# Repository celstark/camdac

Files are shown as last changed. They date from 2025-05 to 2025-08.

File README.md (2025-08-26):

# camdac
DSP / DAC and headphone amplifier based on a Raspberry Pi and CamillaDSP
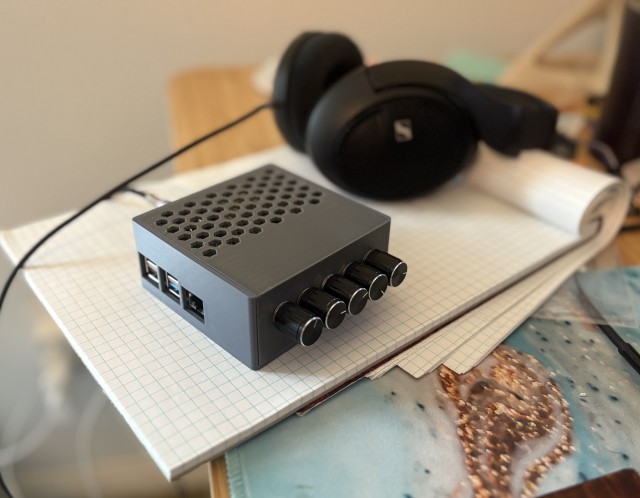
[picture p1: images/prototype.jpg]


**Status**: This is in the "tinkerer" phase. Things are up and running just fine (see the notes.md for the current punch-list). But, expect to do things like ssh onto the device to start up the knob control script (`camdac.py`) and use a browser to the onboard Camilla GUI server to re-define your filters. You don't need the Pi physically hooked to anything but USB power if you want to stream to it. But, you can customize the knobs to do whatever aspects of EQ you like. Heck, you can skip the onboard DAC HAT and just use "Gadget mode" to process from USB to USB.

**August 2025**: Big update here is the addition of a display, a new case to go along with it, and allowing the filter knobs to switch what aspect you're controling (gain, freq, Q, and type)
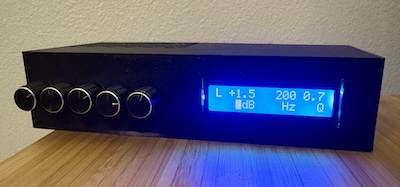
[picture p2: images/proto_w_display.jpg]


## What is it?  Why is it?
I like knobs. I like EQ. When I started in audio, we EQ'ed with knobs. I yearn for that simpler time. So, I made this overly-complex solution to that problem ;)

OK, a better answer.  CamDAC is a project that lets you construct a device to give your audio system stand-alone, fully-customizable DSP processing for things like parametric EQ. It's based off of a Raspberry Pi running [CamillaDSP](https://github.com/HEnquist/camilladsp), a very efficient DSP processing utility. While it runs in software on Linux, macOS, and Windows (meaning you could just run it in software), CamDAC gives you a physical device with physical adjusters. A few use-modes:
- Given that this is a Raspbery Pi, it can house our mount network-based music shares and you can have it directly stream from there with parametric EQ pushing audio out the RCA jacks or the headphone jack
- Given that, you can run Shairplay and stream from your iPhone, iPad, etc. or any other Airplay device and have lossless streaming with parametric EQ
- You can have USB input and USB output, turning this into an inline digital parametric EQ device.  See *Gadget Mode* below.
- Configure this to your heart's content. Got an EQ profile you overall like for your headphones or speakers, but feel, at times, you want a touch more bass or some more "air"?  Have a mood or an album where you just want nothing to do with upper-bass? Assign these filters to the knobs and have this overlay on top of your existing EQ profile.
- No seriously -- to your heart's content.  Want a knob that simultaneously adds a low-shelf and a high-shelf filter at once (make me a V!)? Want one that adjusts the Q of a filter rather than it's amplitude? Heck, want to turn a knob that both adjusts that V shaped response while also adjusting the Q of the slopes and varies the amplitude of a notch centered on 3.14 kHz? Go for it.  You're strange, sure, but go for it.
- *Remember, you can have more filters than knobs*. For example, I've got mine setup right now with 6 filters for my headphones as the basic starting point. In addition to those, I've got 4 more filter knobs giving me several different shelf or peaking filters to play around with. So, I start off with my current go-to EQ setup for these headphones, but have other adjustments I can add in (in addition to giving volume and balance knobs).

## What do I need?
You'll need the following to construct the device:
- A Raspberry Pi 4.  You can likely use others, but it's setup now for the 4B
- (semi-optional): A DAC HAT. This plugs onto the RPi board and gives you RCA and headphone outputs. It's configured now for the [Raspberry Pi DAC+](https://www.raspberrypi.com/products/dac-plus/) (formerly the IQAudio DAC+). If you use this as a USB gadget only (PEQ on USB in to USB out), you don't need this.
- A micro USB card for the RPi.  I got a 64G one for $5 and I've used under 10G on it.
- USB power for the Pi. I'm using some USB-C Apple wall supply I had around. Max it'll need ever is 3A @ 5V, but I've run it happily on a 1.5A 3V supply.
- A case: I've provided STL and SCAD files for what I've made
- Rotary encoders: Just the basic ones (not the modules) are all you need
- A way to wire the encoders to the GPIO pins. I used a simple off-the-shelf GPIO breadboard that made it easy.  More details are in the `GPIO_lines.md` file. But, you'll need a basic soldering setup
- A lack of paralyzing fear when looking at code. I've written a bunch here and more instructions may come, but the whole point here is to be able to customize this and that does mean being able to change things in a text file

All-in, I'm under $100 USD

# OK, where do I start?
## Get your RPi going and CamillaDSP on it
Assuming you've got your parts, you'll need to install the RPi OS, Camilla DSP, and, optionally Shairpoint. Fortunately, someone's written all that up for us and done a great job.  All hail _mdsimon2_!.  Seriously, just go follow [mdsimon2's instructions](https://github.com/mdsimon2/RPi-CamillaDSP). It'll start off having you do things like this once the OS is installed:

```
mkdir ~/camilladsp ~/camilladsp/coeffs ~/camilladsp/configs
wget https://github.com/HEnquist/camilladsp/releases/download/v3.0.1/camilladsp-linux-aarch64.tar.gz -O ~/camilladsp/camilladsp-linux-aarch64.tar.gz
sudo tar -xvf ~/camilladsp/camilladsp-linux-aarch64.tar.gz -C /usr/local/bin/

sudo wget https://raw.githubusercontent.com/mdsimon2/RPi-CamillaDSP/main/camilladsp.service -O /lib/systemd/system/camilladsp.service

... (keep going )

```
I did Steps 1-7 but skipped Step 8 (gadget mode) initially as I didn't have the required hardware (See below -- it's running now). Two big things:
1) **For Sep 7, Enable ALSA Loopback**, you are running in ALSA mode. So, setup that loopback
2) **When it comes to Step 9, Assign the Active Configuration**, use the `CamDAC_config.yml` file here. It's got all you need to get going (see below) 

Note, if you've followed the dfault paths here, on your host machine, you should be able to connect to the CamillaDSP GUI using a web browser on port 5005. This can be super, super handy as you can monitor just what's going on with Camilla.

While we're here, we have one more thing to do. That guide assumes you're using the headphone jack on the Pi board itself. We're using the much nicer [TI 5122](https://www.ti.com/document-viewer/pcm5122/datasheet) one. To do this, we need to turn off the onboard sound by commenting out the audio with `#dtparam=audio=on` in `/boot/firmware/config.txt`. If you get lost here, check the [RPi DAC docs](https://www.raspberrypi.com/documentation/accessories/audio.html) 

While here, you may want to install Shairport. This lets you Airplay (lossless WiFi) to your box.  That's included in [mdsimon2's Streamer Applications](https://github.com/mdsimon2/RPi-CamillaDSP?tab=readme-ov-file#streamer-applications) section of the instructions.

FWIW, setting up a Remote Desktop (VNC is baked in) is optional. I found it handy when trying to debug my audio devices a bit as it gave an easy way of changing the default, but it really is just optional. For all the development work, I'm just using VSCode and an ssh remote onto the device. Currently, if you do the VNC route, actually use TigerVNC. Remmina and some others have issues.

Once everything is set and you've done a reboot, test it out.  A quick test for Camilla's basic operation and the DAC HAT's operation, try this on the command line: `speaker-test -D hw:Loopback,1 -c 2 -r 44100 -F S32_LE`.  You're telling Linux to send pink noise to the ALSA Loopback device. The `CamDAC_config.yml` that should be running in your Camilla DSP interface is listening on the hw:Loopback and sending to the DAC HAT. In their lingo, the capture device is `hw:0` and the DAC HAT is `hw:CARD=DAC,DEV=0`. A [screencap](images/camilla_config.png) sample running configuration in the Camilla DAC GUI is provided here in the images folder. If things are working, don't worry yet about the other parameters. You're doing your're processing at 88.1k and you're setup to adjust the sample rate as needed. There's plenty of time to geek out on this later after going over the main [Camilla DSP docs](https://github.com/HEnquist/camilladsp)

## Install pyCamillaDSP
The code here uses [pyCamillaDSP](https://henquist.github.io/pycamilladsp/config/) as a Python front-end to Camilla's web-sockets so we can control Camilla. If that means nothing to you, forget I typed it. We need a Python library to be installed so that our code can work. Unlike a simple pip-based install, this *really* wants to be in a virtual environment and not be installed into the main system python. Here's how you do that and install the library (make sure though to include the system packages or you'll miss out on all the RPi bits we need).
```
python -m venv  --system-site-packages ~/camilladsp/.venv
source ~/camilladsp/.venv/bin/activate
pip install git+https://github.com/HEnquist/pycamilladsp.git
```

With that done, as you work with the code, you'll need to either first activate the environment (that `source ~/camilladsp/.venv/bin/activate` bit) or just tell Linux to use that environment's python and run the code with `~/camilladsp/.venv/bin/python some_script.py`. So, to run the CamDAC now, before we have any service running, you can just `~/camilladsp/.venv/bin/python camdac.py`

## Wire up your encoders
I've covered my configuration of the GPIO lines and how I wired things up in the [GPIO_lines.md](GPIO_lines.md) file. Head over there for the details.

## Case
The case came from [Pieterbos82](https://www.thingiverse.com/thing:4753525) on Thingiverse originally.  I took his SCAD code, fumbled my way through SCAD, and revised it.  Notably, I turned off the Neutrik / XLR bits, reworked the DAC HAT spacing for the IQAudio / RaspberyPi branded DAC boards, and added holes in the "front" for our controls. The STL and SCAD files are all included here for printing or modification.

## Test out your hardware
Once built, you'll want to make sure the encoders are working correctly.  The supplied `encoder_tester.py` will do this for you. Run it with `~/camilladsp/.venv/bin/python ~/camdac/encoder_tester.py`.  You should be able to adjust all your knobs and have the code report your chages. Press each button and check it too. Hold down the first knob to exit (or Ctrl-C)

# Customizing your rig
Still here?  Now, for the fun.  It's time to make those knobs do what you want.  There are two places to work in and consider here: the `camdac.py` file that actually talks to CamillaDSP and the `CamDAC_config.yml` file.

## The CamDAC_config.yml file
This is the configuration file for CamillaDSP tied to the project. After installing Camilla DSP, copy it into the `~camilladsp/configs/` folder if it's not already there from above.  Assuming you've got the CamillaDSP GUI running (you did install that above right? - it'll be somewhere like http://raspberrypi.local:5005/gui), go to the Files tab, load this up and set it to be "active" (starred)

You can customize this in a text editor or in the CamillaDSP GUI. There are a few key bits here:
- We have filters named "Filt1", "Filt2", ... "Filt5".  These are ones, by default, configured to be accessible by `camdac.py` and be adjusted with the knobs. You can use different names if you like, but just know that `camdac.py` needs to send configuration updates for the active config that match these names.  Best to set their default gain, initially at least, to zero. But, **here is where you actually set things like the frequency and Q**.  The `camdac.py`, by default, just changes the amplitude of these filters.
- There's an example "LShelf" filter. You'll have some filters you want always in the pipeline.  Think of these as your "base configuration" if you like and the FiltN as what rides on top of these. Setup whatever you like here in the Filters section and add it to the Pipeline as well.
- We have separate volume filters for L and R to give our balance. They work by using the Aux sliders to reduce gain in one or the other channel

## The camdac.py file
At some point, this will be tied to a system service, but for now, it's just a file to run manually. But, it does all our heavy-lifting.  At the outset, we have some simple constants saying how much we want each click of the encoder to adjust the volume or an EQ filter:
```
volume_step = 0.25
balance_step = 0.05
eq_step = 0.5
```
After that, you'll start seeing some notes to you saying where you're more or less likely to find things to customize. The first one to look at is to check the `encpins` and adjust if you put your knobs on different GPIO lines. Next, you'll see declarations of our kobs.

That section lays out some defaults to pay attention to. Most notably, the `name` attribute says what each knob starts off acting like. You can adjust things here if you like, but further down, we get to the "Setup what the knobs and buttons actually do" where you can override things.

The key to note here is that how the knob behaves is goverend by the `name` attribute. `Volume` makes it control the main volume.  `VolBal` has it toggle (based on press) between Volume and Balance. Anything else is the name of a filter it'll try to control the amplitude of.  We trap both clockwise and counter-clockwise events so we can know the direction and we turn what `gpiozero` normally has as just simple functions into lambda ones so that we cana include optional parameters with info about not just the `gpiozero` encoder that made the event, but that direction and our higher-level Encoder class that it's tied to.  I'm passing all this in to give us the most flexibility in what we want the knobs to be able to do.

# Misc bits
A few utilities to help here:
- `encoder_tester.py`: Lets you watch your encoder events to make sure all is working
- `fetch_config.py`: Dumps the running configuration to files and shows you an EQAPO style filter configuration

# Gadget mode
You don't need to use any onboard DAC. You can just as well use the device as an in-line digitial PEQ device. 

- Figure your current DAC's capable modes. If it's plugged into a Linux box `aplay -l` to list the devices. In my case, the Fulla was on card1.  Then, see what modes are supported `cat /proc/asound/card1/stream0`.  So, all typical suspects from 44100 - 384000, 16_LE, 24_3LE, and 32_LE

- Set the RPi up to run in gadget mode and offer up an audio interface. Instructions are ocming from [mdsimon2](https://github.com/mdsimon2/RPi-Camilla). It's also good to have [DeLub's post on ASR](https://www.audiosciencereview.com/forum/index.php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) on hand (we're well past the need to compile anything in that thread though). For now, I'm just going to offer up 44100 like mdsimon2 did 
```
echo 'dtoverlay=dwc2' | sudo tee -a /boot/firmware/config.txt > /dev/null
echo -e 'dwc2\ng_audio' | sudo tee -a /etc/modules > /dev/null
echo 'options g_audio c_srate=44100 c_ssize=4 c_chmask=3 p_chmask=0' | sudo tee -a /etc/modprobe.d/usb_g_audio.conf > /dev/null 

sudo reboot now
```
- Use the USB-C power/data splitter. Power supply goes into power (duh), USB2 data goes to your computer, USB/data goes to Rpi.  On the RPi then, have a USB2 port go to your DAC.  You should get your USB chime.  If you're on a Linux host, you should see a "Linux USB Audio Gadget" with `aplay -l` or `lsusb`. You should see the audio format available as well with `cat /proc/asound/card1/stream0` (change card1 to yoru card number from aplay or lsusb) 
- On the RPi, we need to setup CamillaDSP to now be able to listen to this input, do its DSP, and then send out.
  - Run `aplay -L` and look for your DAC. It'll give a big list of possible devices. I've been having Camilla output to `hw:CARD=DAC` to send audio to my RPi DAC.  Look for an "hw" one that shows your device.  Mine is `hw:CARD=Schiit`. It may help to run `aplay -L | grep hw` to filt out and just get the "hw" ones.
  - In that `aplay -L` you should see `usbstream:CARD=UAC2Gadget` (or possibly hw:UAC2Gadget`)
  - In the CamillaDSP GUI, head to Files, enter in "gadget" or some such name at the bottom of the Configs panel, hit Save and star it to mark as active.  
  - In its Devices, set: samplerate=44100 (if you're resampling, you should be able to keep that at your 88200 or whatever you like too), capture device / device = "hw:CARD=UAC2Gadget" (even if it showed as _usbstream_), and Playback device / device = "hw:NAME".  In my case, it was `hw:Schiit` (you can also use `hw:CARD=Schiit`)

FWIW, another great project by [Wang-Yue](https://github.com/Wang-Yue/CamillaDSP-Gadget) is targeted at just this kind of mode of operation, but without hardware knobs.  And we all know, I like knobs.

# Displays
There are a few ways to add a display. If you want something full-featured, we've always got the HDMI outputs. But, we can make a simple display out of an LCD or LED module using the I2C protocol. A great thing about this is that the same pair of data lines that the DAC module uses for basic communication can be used here as the protocol supports multiple devices, so long as they've got different IDs. I used `RPi_I2C_driver.py` from [DenisFromHR](https://gist.github.com/DenisFromHR/cc863375a6e19dce359d) here for the 1602, but there are loads of options.

## Display options
I've tried out both a generic 1602 (16x2 LCD; seems to be a [Z-0234](https://wiki.52pi.com/index.php?title=Z-0234)) modules and a generic 128x32 OLED (based on an SSD1306 chip). Honestly, the 128x32 OLED seems more a pain than it's worth. The one I got is tiny and you really need to treat it like an image device. The `adafruit-circuitpython-ssd1306` library seems nice enough and if you want something fancy like showing the EQ curve, this would be the right approach.  The 1602 works for what I want.

### LCD 1602 voltage
The 1602 setup is designed to run off of 5V and you'll see lots of concerns out there about this and the fact that the Pi operates at 3.3V. Doom, gloom, fear of letting the smoke out of your Pi's chips, etc. abound. There's a [great writeup](https://forums.raspberrypi.com/viewtopic.php?t=313458) about this that even specifically covers the 8574T I2C multiplexer we've got on these boards. The TL;DR is that things are safe, but long cable runs / bad environments could be an issue performance-wise. If so, use a logic level converter (these are super cheap -- like under a dollar for a 4-line converter). But here, the 1602s with those 8574T have the pull-up resistors on the Pi side, so the SDA and SCL lines run at the Pi's 3.3V, not the 5V of the display board (I verified this with an oscilloscope). So, if your display is working properly with the 5V in and data lines run at 3.3V, you're fine. If it starts getting garbled data, put in the logic level converter. Or, be paranoid and run the display at 3.3V turning the contrast all the way down to let you see anything (how I started off). 

BTW, if you're wondring, the little jumper on that 1602 board is to enable / disable the backlight entirely.  

## Finding your display's ID
Odds are you can skip this by either running with the default address or just checking the docs on your module to see what it uses. But, seeing as how the docs on these are pretty ... lean, you can ask your Pi what the module has registered itself as. Hook up the display (SDA, and SCL lines will be shared with the DAC; 5V or 3.3V and GND are the only others needed), power up the Pi and run `sudo i2cdetect -y 1`.  You'll likely see a "UU" in the resulting matrix that you can read out as being in location 4c. That just means we've got a driver loaded for a device at that address.  That's the I2C address of the DAC.  See a hex code somewhere else? That's the address of your display.  My 1602 comes up on 0x27 and the 128x32 OLED comes up on 0x3c. If you're not on 0x27, edit the `RPi_I2C_driver.py` file.

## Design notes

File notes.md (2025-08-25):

# Case to improve
- ~~You need to remove the SD card to get the board in and out.  1 mm more and we'd clear~~
- ~~Different knobs, 4 controls, or a bit bigger case -- it's a bit cramped~~

# Software to-do
- Getting clicks between tracks at least with Shairplay. (Seems to be tied to the DAC HAT)
- Handle offset / pre-amp gain. Right now, the main Volume knob handles this but we could limit it or use the Aux ones I'm using for balance to ensure you never go above -X dB. (Pipeline goes resampler, master volume, PEQ knob filters, balance, fixed PEQ filters)
- Run `camdac.py` as a service
- Add ability to re-define filters more easily
- Setup better handling of multiple bit rates

# Hardware to-do
- ~~USB "gadget" mode for inline digital PEQ~~
- ~~Add display for feedback~~

-----------
Desktop audio not working -- https://github.com/HEnquist/camilladsp-config
- Put their asound.conf into /etc/
-

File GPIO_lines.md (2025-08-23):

# Pinout

## Pins in use
The IQAudio / [Raspberry Pi branded DACs](https://www.raspberrypi.com/documentation/accessories/audio.html) all use GPIO 2 (SDA / I2C), 3 (SCL / I2C), and 18-21 (I2S). For the DAC PRO and DAC+, the rest are open. For the DigiAMP+ or Codec, they also use 22 (mute / unmute), 22 & 23 (rotary encoder or LED), 25 (IR sensor), and 27 (switch).  The Codec really doesn't seem to apply to this project, but the DigiAMP+ board might be used. So, if you're using the *DigiAMP+ (or another board) revisit the default IO piols*.

## Pins open
After this, though, we should have 17 pins open to us: 4, 5, 6, 7, 8, 12, 13, 14, 15, 16, 17, 22, 23, 24, 25, 26, and 27. If you do a full rotary-encoder + switch setup, you need 3 pins per encoder (2 for the encoder and 1 for the switch) meaning you can have 5 encoders going and still have 2 IO pins left for LED indicators (e.g., showing the mode a switch is in) or something else. 

## Default assignment
To simplify the wiring a bit, for the 5-encoder + switch version I've grouped things for the GPIO prototype breadboard HAT I picked up as follows (A, B, _SW_):
1) 12, 13, _16_
2) 7 (CE1), 5, _6_
3) 9 (MISO), 11 (CLK), _8_ (CE0)
4) 24, 25, _10 (MOSI)_
5) 27, 22, _23_

So, in the code, for example, the right-most encoder knob, #5, uses pins 27 (A) and 22 (B) for the dial and 23 for the switch.

## I2C
Note, we can use the same I2C lines that the DAC is using for an optional display

# Resistors and wiring
We can likely get away without using pull-up resistors and just make sure the internal ones are enabled. The Pi has ~50k resistors baked into it, but its input impedance isn't far off that. For "strong" setting of the IO pins capable of working in noisy environments (e.g., with longer cable runs), you may want the resistor to be a tenth the input impedance and the internal ones are closer then to 1:1.  Ignoring them does simplify the hardware a touch as the board I picked does make including them not very elegant. Note, if you use modules rather than raw encoders, these typically have 10k resistors going between the Vcc and the junction between the data lines (CLK, DT, and SW) and their respective switches (the other end of each switch is on GND). Thus, the modules, are in a pull-up state and when the switches close, it gets pulled down.

But, here, we're going to go with using the internal ones. The `gpiozero` library has the default `pull_up` as True for buttons (wanting you to wire one end to the GPIO and the other to GND) -- i.e., it's engaging the internal pull-up resistors unless you manually set the `pull_up` paramter to _floating_.  For the rotary encoders, it expects the "A" and "B" data pins to go to GPIO and the "C" (common) to go to GND.  For any LEDs you choose, put something like a 300Ω resistor in series with it to limit the current and then directly hook it between the GPIO data line and GND.

If using basic encoders (non-modules):
- Solder a wire to the "A" terminal (leftmost of the 3 if looking from the front) and hook to the first number above
- Solder a wire to the "B" terminal (rightmost of the 3 if looking from the front) and hook to the second number above
- Strip ~2cm off another wire and use that to connect the "C" terminal (middle of the 3) and one side of the switch (either of the 2) thus jumpering them on the encoder end. Bring that wire and hook to the ground bus
- Solder a wire to the other end of the switch (the one you didn't jumper above) and hook that to the third number above.

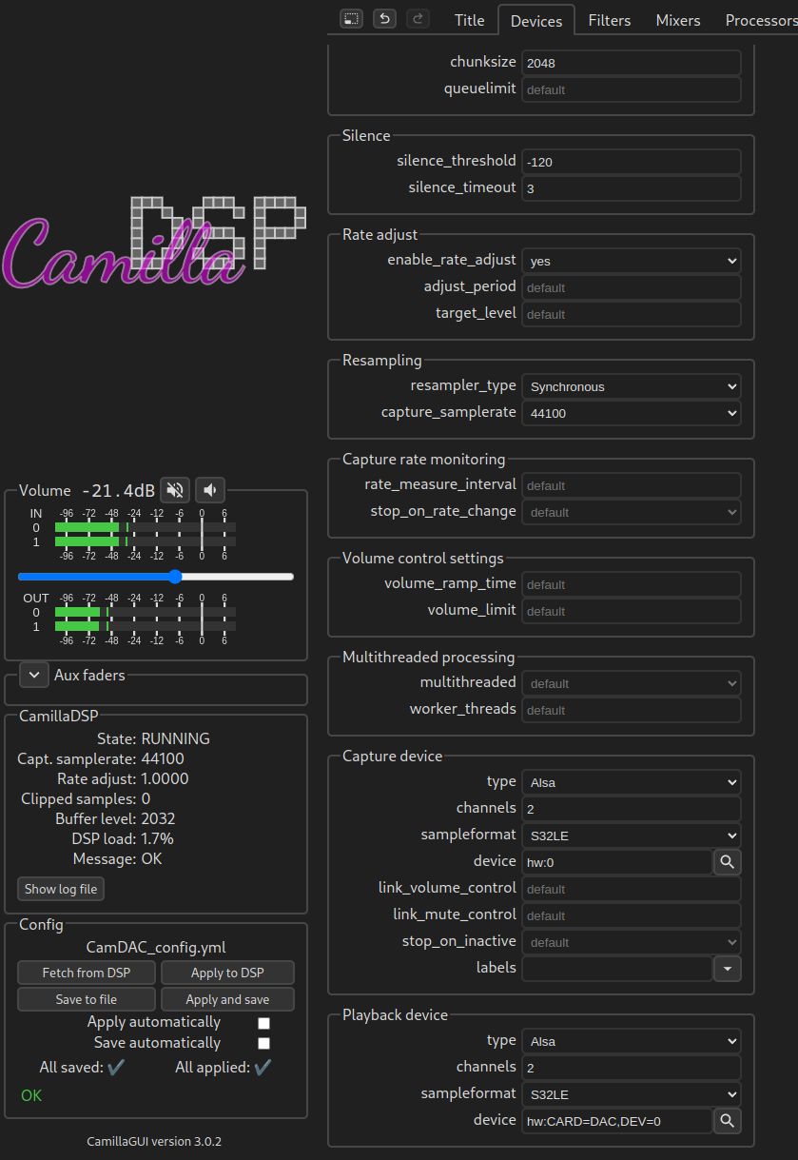
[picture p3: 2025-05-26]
images/camilla_config.png

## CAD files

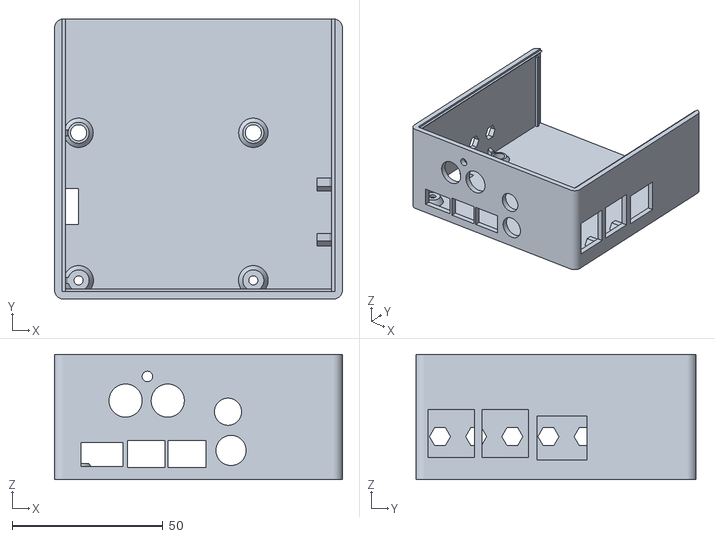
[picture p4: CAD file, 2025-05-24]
CS_case_v1_body.stl
95.6 x 93.0 x 41.5

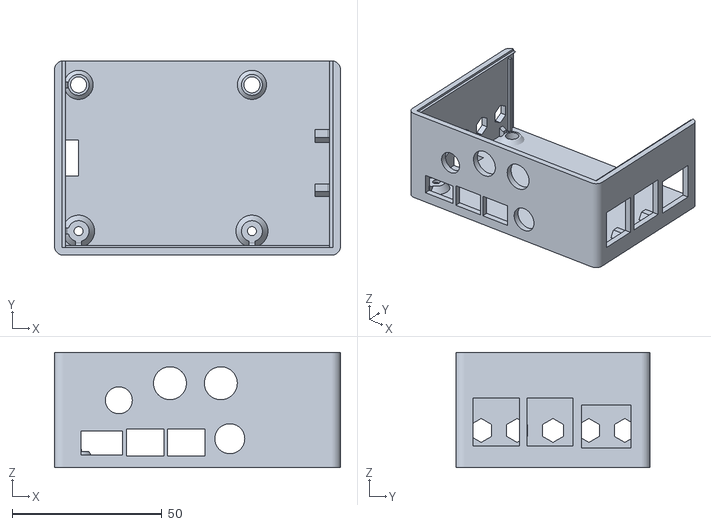
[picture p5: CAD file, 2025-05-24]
CS_case_topslider_v1.stl
95.6 x 65.0 x 38.5

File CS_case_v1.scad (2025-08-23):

//include <hinge.scad>

$fn=80;




//
//#


with_sdslot=true;

bottom_thickness=2.5;
rpi4_width= 56;
rpi4_length=85;
rpi4_edge_to_left_hole=3.5;
rpi4_edge_to_top_hole=3.5;
rpi4_edge_to_right_hole=58+3.5;

//height=with_xlr ? xlr_in_side_low? 39: 66:36;
height=39;
length=95.6;
width = rpi4_width+bottom_thickness*2+32;
echo ("h: ",height, "w: ",width);




width_tolerance=0.2;

pi_move=[-0.8,-((width-rpi4_width)/2-bottom_thickness)+width_tolerance,0];
move_pi=-pi_move[1];



straight_hole_rim=0.8;
extra = 0;

screw_hole_radius=1.5;
screw_head_radius=2.67;
screw_head_depth=4.15;

corner_edge_radius = 3;

//hinge-parameters
horizontal_distance=3;
hinge_radius=2;
number_of_hinge_parts=8;
extra_hinge_corner_height=1;
hinge_tolerance=0.3;

//ventilation hole tuning. Not complete
holes_in_back=false;
holes_in_side=true;
vertical_number_of_holes=4;
horizontal_number_of_holes=5;
hole_radius=3.5;
hole_rim=1.3;
vertical_hole_rim = 7;

//xlr_height=47.5;

top_rail_thickness=2.5;
rail_radius=0.9;
vertical_rail_width=1.2;

// CELS - add encoders
with_encoders = true;

//slide or hinge
top_type="slide";


//some calculations depending on the variables before
side_height = top_type == "slide" ? 
    height + bottom_thickness 
    : height;
side_translate_height = top_type == "slide" ?
            (height)/2
            :(height-bottom_thickness)/2;

//"top" or "case" or "all"
part = "top";
if(top_type == "hinge") {
    rotate([90,0,0])
    case();
} else if (top_type == "slide" && part == "top") {
    rotate([-90,0,0])
    case();
} else {
    case();
}

module case() {
    difference() {
        union() {
            if(part == "all" || part == "case") {
                bottom();
                
                difference() {
                    front();
                    pi4_holes_front();
                }
                
                difference() {
                    sides();
                    pi4_holes_side();

                }
                color("brown")
                board_supports();
                holes_outer();
            }

            
        }
                   
        if(part == "all" || part == "case") {
            if (with_sdslot) {
                sd_card_slot();
            }
            holes_inner();
            if(top_type=="slide") {
           //     back_lips(0.05);
            }
        }
        
    }
    
    if(part == "all" || part == "top") {            
        top();        
        difference() {

            back();
            holes_inner();
        }
    }
}



module back_lips(extra=0) {
    x_distance_from_edge = 2.2;
    distance_from_edge = 8.05;
    distance_from_utp = 29.6;
    tolerance=0.2;


    height=1.2+extra;
    radius=3.5+extra;
    lip_length=width-rpi4_width-bottom_thickness-width_tolerance+radius;
    higher_lip_length=width-rpi4_width-bottom_thickness*2+width_tolerance;
    
    //left
    color("green")
    translate_back_left_hole([0,0,5.3-height-1.25])
    cylinder(r=radius, h=height+extra, center=false);
    
    translate_back_left_hole([0,lip_length/2,5.3-(height+extra)/2-1.25])
    cube([radius*2,lip_length, height+extra], center=true);
    //higher part
    translate_back_left_hole([0,higher_lip_length/2+rpi4_edge_to_top_hole+tolerance,5.3-1.25])
    cube([radius*2,higher_lip_length, 2.5], center=true);


    //right
    color("green")
    translate_back_right_hole([0,0,5.3-height-1.25])
    cylinder(r=radius, h=height+extra, center=false);    
    
    translate_back_right_hole([0,lip_length/2,5.3-(height+extra)/2-1.25])
    cube([radius*2,lip_length, height+extra], center=true);
    
    //higher part
    translate_back_right_hole([0,higher_lip_length/2+rpi4_edge_to_top_hole+tolerance,5.3-1.25]) 
    cube([radius*2,higher_lip_length, 2.5], center=true);
    
    //if(1) { //xlr_side_in_low
    difference() {
        translate([0,(lip_length)/2+move_pi/2+bottom_thickness-0.75,bottom_thickness+0.1])
        cube([length-bottom_thickness*2-vertical_rail_width*2-tolerance, lip_length-radius*2+1.5, bottom_thickness-0.05], center=true);
        holes_outer(extra=0.13);
    }
    //}

}

module translate_front_left_hole(extras=[0,0,0]) {   
    translate([-rpi4_length/2+rpi4_edge_to_left_hole+extras[0]+pi_move[0],
        -rpi4_width/2+rpi4_edge_to_top_hole+pi_move[1]+extras[1],
        extras[2]])
    children();
}

module translate_back_left_hole(extras=[0,0,0]) {
    translate([-rpi4_length/2+rpi4_edge_to_left_hole+extras[0]+pi_move[0],
        rpi4_width/2-rpi4_edge_to_top_hole+pi_move[1]+extras[1],
        extras[2]])
    children();
}

module translate_front_right_hole(extras=[0,0,0]) {
    translate([-rpi4_length/2+rpi4_edge_to_right_hole+extras[0]+pi_move[0],
        -rpi4_width/2+rpi4_edge_to_top_hole+pi_move[1]+extras[1],
        extras[2]])
    children();
}

module translate_back_right_hole(extras=[0,0,0]) {
    translate([-rpi4_length/2+rpi4_edge_to_right_hole+extras[0]+pi_move[0],
        rpi4_width/2-rpi4_edge_to_top_hole+pi_move[1]+extras[1],
        extras[2]])
    children();
}

module holes_outer(extra = 0) {

    distance_from_edge = 8.05;
    distance_from_utp = 29.6;
    big_radius = 6.2+extra;
    big_radius_back= top_type == "slide" ? 
        7 + extra : 7 + extra;
    radius2 = top_type == "slide" ? 
            3.5 + extra : 3.5 + extra;
    height2 = top_type == "slide" ? 
            5.3 -1.2 + extra: 5.3 + extra;

    color("white")
    translate_front_left_hole([0,0,-1.25])
    cylinder(r1=big_radius,r2=3.5, h=5.3, center=false);
    color("white")
    translate_back_left_hole([0,0,-1.25])
    cylinder(r1=big_radius_back,r2=radius2, h=height2, center=false);


    //front-right
    color("white")
    translate_front_right_hole([0,0,-1.25])
    cylinder(r1=big_radius,r2=3.5, h=5.3, center=false);
    //back-right
    color("white")
    translate_back_right_hole([0,0, -1.25])
    cylinder(r1=big_radius_back,r2=radius2, h=height2, center=false);

}

module board_supports() {
    x_distance_from_edge = 2.5;
    y_distance_from_edge = 7.05;
    distance_from_utp = 29.6;
    
    //viewed from top, UTP to the right:
    //left-top hole, left support   
    
    translate_front_left_hole([-5.55,-1.05,0])
    board_support();
    
    
    //left-top hole, top support
    if(top_type=="hinge") {
        translate([-length/2+x_distance_from_edge+4.5, width/2-y_distance_from_edge+4.6-move_pi, 0])
        rotate([0,0,-90])    
        board_support();
    }
    //left-bottom hole, left support
    difference() {        
        translate_back_left_hole([-5.55,-1.05,0])
        //translate([-length/2+x_distance_from_edge, width/2-y_distance_from_edge-2-move_pi, 0])
        board_support();
        back_lips(extra=0.05);
    }
    
    //left-top hole, bottom support
//    *
//    translate([-length/2+y_distance_from_edge+2, -width/2+x_distance_from_edge-0.05-move_pi, 0])
//    rotate([0,0,90])    
//    board_support();

    //right-top hole, top support    
    if(top_type=="hinge") {
        translate([length/2-distance_from_utp-1, width/2-y_distance_from_edge+4.6-move_pi, 0])
        rotate([0,0,-90])    
        board_support();
    }
    
    //right-bottom hole, bottom support   
//*    
//    translate([length/2-distance_from_utp+1, -rpi4_width/2+x_distance_from_edge-0.05-move_pi, 0])
//    rotate([0,0,90])    
//    board_support();
    
    
    //right-top support
    
    translate([length/2-x_distance_from_edge, rpi4_width/2-y_distance_from_edge-11.5-move_pi, 0])
    rotate([0,0,180])    
    board_support(width=2.7, slope=true);

    //right-bottom support    
    translate([length/2-x_distance_from_edge, -rpi4_width/2+y_distance_from_edge+12-move_pi, 0])
    rotate([0,0,180])    
    board_support(width=2.5, slope=true);
    
}

module board_support(width=2, slope=false) {
 
    top_height=5;
    bottom_height=4.05;

    top_length=1.85;
    length=6;
    extra_cutoff_height=0.75;

    difference() {
        cube([top_length, width, top_height]);

    color("cyan")
            translate([-1.3,-0.1,top_height+extra_cutoff_height])
     rotate([0,30,0])
        cube([top_length*3, width+0.2, top_length*3]);        
       
    }

    cube([length, width, bottom_height]);
    if(slope) {
        
        translate([length,width,bottom_height/2])
        rotate([0,-90,0])
        linear_extrude(height=length, center=false)
         circle(d=bottom_height, $fn=3 );
    }
        
}


module holes_inner() {
    color("white")
    translate_front_left_hole([0,0, -1.3])
    cylinder(r=screw_hole_radius, h=5.8, center=false);
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

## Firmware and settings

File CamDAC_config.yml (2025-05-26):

description: null
devices:
  adjust_period: null
  capture:
    channels: 2
    device: hw:0
    format: S32LE
    labels: null
    link_mute_control: null
    link_volume_control: null
    stop_on_inactive: null
    type: Alsa
  capture_samplerate: 44100
  chunksize: 2048
  enable_rate_adjust: true
  multithreaded: null
  playback:
    channels: 2
    device: hw:CARD=DAC,DEV=0
    format: S32LE
    type: Alsa
  queuelimit: null
  rate_measure_interval: null
  resampler:
    type: Synchronous
  samplerate: 88200
  silence_threshold: -120
  silence_timeout: 3
  stop_on_rate_change: null
  target_level: null
  volume_limit: null
  volume_ramp_time: null
  worker_threads: null
filters:
  Filt1:
    description: Filter 1 for knob control
    parameters:
      freq: 100
      gain: 0
      q: 1
      type: Lowshelf
    type: Biquad
  Filt2:
    description: Filter 2 for knob control
    parameters:
      freq: 2000
      gain: 0
      q: 3
      type: Peaking
    type: Biquad
  Filt3:
    description: Filter 3 for knob control
    parameters:
      freq: 5000
      gain: 0
      q: 4
      type: Peaking
    type: Biquad
  Filt4:
    description: Filter 4 for knob control
    parameters:
      freq: 8000
      gain: 0
      q: 4
      type: Peaking
    type: Biquad
  Filt5:
    description: Filter 5 for knob control
    parameters:
      freq: 12000
      gain: 0
      q: 1
      type: Highshelf
    type: Biquad
  LShelf:
    description: Basic low-shelf -- example of filter that might always be active
    parameters:
      freq: 120
      gain: 0
      q: 0.707
      type: Lowshelf
    type: Biquad
  LVolume:
    description: Left channel balance
    parameters:
      fader: Aux1
      limit: null
      ramp_time: null
    type: Volume
  RVolume:
    description: Right channel balance
    parameters:
      fader: Aux2
      limit: null
      ramp_time: null
    type: Volume
mixers:
  Unnamed Mixer 1:
    channels:
      in: 2
      out: 2
    description: null
    labels: null
    mapping:
    - dest: 0
      mute: false
      sources:
      - channel: 0
        gain: 0
        inverted: false
        mute: false
        scale: dB
pipeline:
- bypassed: null
  channels: null
  description: Filters sent to all channels - can include both knob-based and permanent
  names:
  - Filt1
  - Filt2
  - Filt3
  - Filt4
  - Filt5
  - LShelf
  type: Filter
- bypassed: null
  channels:
  - 0
  description: null
  names:
  - LVolume
  type: Filter
- bypassed: null
  channels:
  - 1
  description: null
  names:
  - RVolume
  type: Filter
processors: null
title: Base config file for CamDAC

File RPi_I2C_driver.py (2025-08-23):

# -*- coding: utf-8 -*-
"""
Compiled, mashed and generally mutilated 2014-2015 by Denis Pleic
Made available under GNU GENERAL PUBLIC LICENSE
# Modified Python I2C library for Raspberry Pi
# as found on http://www.recantha.co.uk/blog/?p=4849
# Joined existing 'i2c_lib.py' and 'lcddriver.py' into a single library
# added bits and pieces from various sources
# By DenisFromHR (Denis Pleic)
# 2015-02-10, ver 0.1
"""
#
#
import smbus
from time import *

class i2c_device:
   def __init__(self, addr, port=1):
      self.addr = addr
      self.bus = smbus.SMBus(port)

# Write a single command
   def write_cmd(self, cmd):
      self.bus.write_byte(self.addr, cmd)
      sleep(0.0001)

# Write a command and argument
   def write_cmd_arg(self, cmd, data):
      self.bus.write_byte_data(self.addr, cmd, data)
      sleep(0.0001)

# Write a block of data
   def write_block_data(self, cmd, data):
      self.bus.write_block_data(self.addr, cmd, data)
      sleep(0.0001)

# Read a single byte
   def read(self):
      return self.bus.read_byte(self.addr)

# Read
   def read_data(self, cmd):
      return self.bus.read_byte_data(self.addr, cmd)

# Read a block of data
   def read_block_data(self, cmd):
      return self.bus.read_block_data(self.addr, cmd)



# LCD Address
ADDRESS = 0x27

# commands
LCD_CLEARDISPLAY = 0x01
LCD_RETURNHOME = 0x02
LCD_ENTRYMODESET = 0x04
LCD_DISPLAYCONTROL = 0x08
LCD_CURSORSHIFT = 0x10
LCD_FUNCTIONSET = 0x20
LCD_SETCGRAMADDR = 0x40
LCD_SETDDRAMADDR = 0x80

# flags for display entry mode
LCD_ENTRYRIGHT = 0x00
LCD_ENTRYLEFT = 0x02
LCD_ENTRYSHIFTINCREMENT = 0x01
LCD_ENTRYSHIFTDECREMENT = 0x00

# flags for display on/off control
LCD_DISPLAYON = 0x04
LCD_DISPLAYOFF = 0x00
LCD_CURSORON = 0x02
LCD_CURSOROFF = 0x00
LCD_BLINKON = 0x01
LCD_BLINKOFF = 0x00

# flags for display/cursor shift
LCD_DISPLAYMOVE = 0x08
LCD_CURSORMOVE = 0x00
LCD_MOVERIGHT = 0x04
LCD_MOVELEFT = 0x00

# flags for function set
LCD_8BITMODE = 0x10
LCD_4BITMODE = 0x00
LCD_2LINE = 0x08
LCD_1LINE = 0x00
LCD_5x10DOTS = 0x04
LCD_5x8DOTS = 0x00

# flags for backlight control
LCD_BACKLIGHT = 0x08
LCD_NOBACKLIGHT = 0x00

En = 0b00000100 # Enable bit
Rw = 0b00000010 # Read/Write bit
Rs = 0b00000001 # Register select bit

class lcd:
   #initializes objects and lcd
   def __init__(self):
      self.lcd_device = i2c_device(ADDRESS)

      self.lcd_write(0x03)
      self.lcd_write(0x03)
      self.lcd_write(0x03)
      self.lcd_write(0x02)

      self.lcd_write(LCD_FUNCTIONSET | LCD_2LINE | LCD_5x8DOTS | LCD_4BITMODE)
      self.lcd_write(LCD_DISPLAYCONTROL | LCD_DISPLAYON)
      self.lcd_write(LCD_CLEARDISPLAY)
      self.lcd_write(LCD_ENTRYMODESET | LCD_ENTRYLEFT)
      sleep(0.2)


   # clocks EN to latch command
   def lcd_strobe(self, data):
      self.lcd_device.write_cmd(data | En | LCD_BACKLIGHT)
      sleep(.0005)
      self.lcd_device.write_cmd(((data & ~En) | LCD_BACKLIGHT))
      sleep(.0001)

   def lcd_write_four_bits(self, data):
      self.lcd_device.write_cmd(data | LCD_BACKLIGHT)
      self.lcd_strobe(data)

   # write a command to lcd
   def lcd_write(self, cmd, mode=0):
      self.lcd_write_four_bits(mode | (cmd & 0xF0))
      self.lcd_write_four_bits(mode | ((cmd << 4) & 0xF0))

   # write a character to lcd (or character rom) 0x09: backlight | RS=DR<
   # works!
   def lcd_write_char(self, charvalue, mode=1):
      self.lcd_write_four_bits(mode | (charvalue & 0xF0))
      self.lcd_write_four_bits(mode | ((charvalue << 4) & 0xF0))
  

   # put string function
   def lcd_display_string(self, string, line):
      if line == 1:
         self.lcd_write(0x80)
      if line == 2:
         self.lcd_write(0xC0)
      if line == 3:
         self.lcd_write(0x94)
      if line == 4:
         self.lcd_write(0xD4)

      for char in string:
         self.lcd_write(ord(char), Rs)

   # clear lcd and set to home
   def lcd_clear(self):
      self.lcd_write(LCD_CLEARDISPLAY)
      self.lcd_write(LCD_RETURNHOME)

   # define backlight on/off (lcd.backlight(1); off= lcd.backlight(0)
   def backlight(self, state): # for state, 1 = on, 0 = off
      if state == 1:
         self.lcd_device.write_cmd(LCD_BACKLIGHT)
      elif state == 0:
         self.lcd_device.write_cmd(LCD_NOBACKLIGHT)

   # add custom characters (0 - 7)
   def lcd_load_custom_chars(self, fontdata):
      self.lcd_write(0x40);
      for char in fontdata:
         for line in char:
            self.lcd_write_char(line)         
         
   # define precise positioning (addition from the forum)
   def lcd_display_string_pos(self, string, line, pos):
    if line == 1:
      pos_new = pos
    elif line == 2:
      pos_new = 0x40 + pos
    elif line == 3:
      pos_new = 0x14 + pos
    elif line == 4:
      pos_new = 0x54 + pos

    self.lcd_write(0x80 + pos_new)

    for char in string:
      self.lcd_write(ord(char), Rs)
   

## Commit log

2025-05-24 Added STL and SCAD files for the case
    The SCAD file lets you generate either STL. These started with pieterbos82's design on Thingiverse: https://www.thingiverse.com/thing:4753525
    [CS_case_topslider_v1.stl, CS_case_v1.scad, CS_case_v1_body.stl]
2025-05-24 Create GPIO_lines.md
    Added info on wiring up encoders and the default GPIO pin use
2025-05-25 Added script to test encoders and buttons
2025-05-25 tuning up encoder code
2025-05-25 reworked to use simple class
    [encoder_tester.py]
2025-05-25 Added toggle_mode to Encoder
2025-05-26 Add utility to read/save config and filter settings
2025-05-26 Debug logging of filter changes
2025-05-27 Fixed bug w knob5
    [camdac.py]
2025-05-30 Clean code and add reset on hold
    [camdac.py]
2025-08-22 Cleaned up case code
    [CS_case_v1.scad]
2025-08-23 Update 1602 voltage text
2025-08-25 Display added and enhanced filter knobs
